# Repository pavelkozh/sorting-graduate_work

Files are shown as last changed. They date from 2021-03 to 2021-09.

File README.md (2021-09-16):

# Проект сортировочного автомата, выполненного на базе микроконтроллера AVR ATmega328P.
Автомат осуществляет сортировку цветных объектов в реальном времени, распределяя их по отдельным емкостям.
Пример работы автомата:



### Алгоритм работы автомата

1. Считывание цвета объекта, проходящего мимо датчика цвета в канале автомата.
2. Формирование очереди объектов для сортировки.
3. Сортировка объектов очереди по принципу FIFO (First Input First Output) с одновременным сдвигом очереди.

Очередь объектов пополняется в режиме реального времени. Сортировка происходит путем подачи последовательности управляющих воздействий на серводвигатели, осуществляющие выталкивание очередного объекта из накопителя и вращение платформы с емкостями.

### Алгоритм формирования очереди объектов

1. Формирование выборки измерений цвета с периодом 2.5 мс и преобразование измерений цветовой модели RGB в цветовую модель HSV.
2. Обработка выборки измерений (для увеличения вероятности верного определения цвета).
3. Добавление объекта в массив очереди.

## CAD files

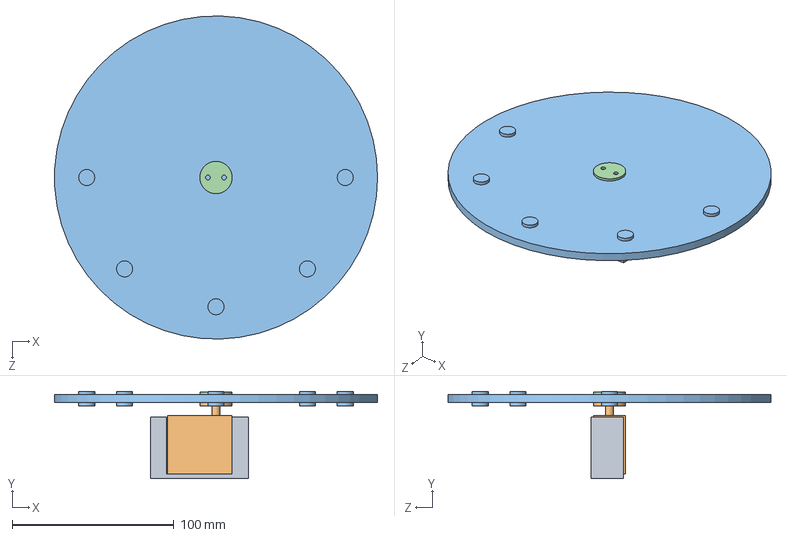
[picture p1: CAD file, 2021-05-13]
blueprints/Сборка2.SLDASM
200.0 x 54.0 x 199.9 mm
for_servo
MG996R
Диск
Шайба

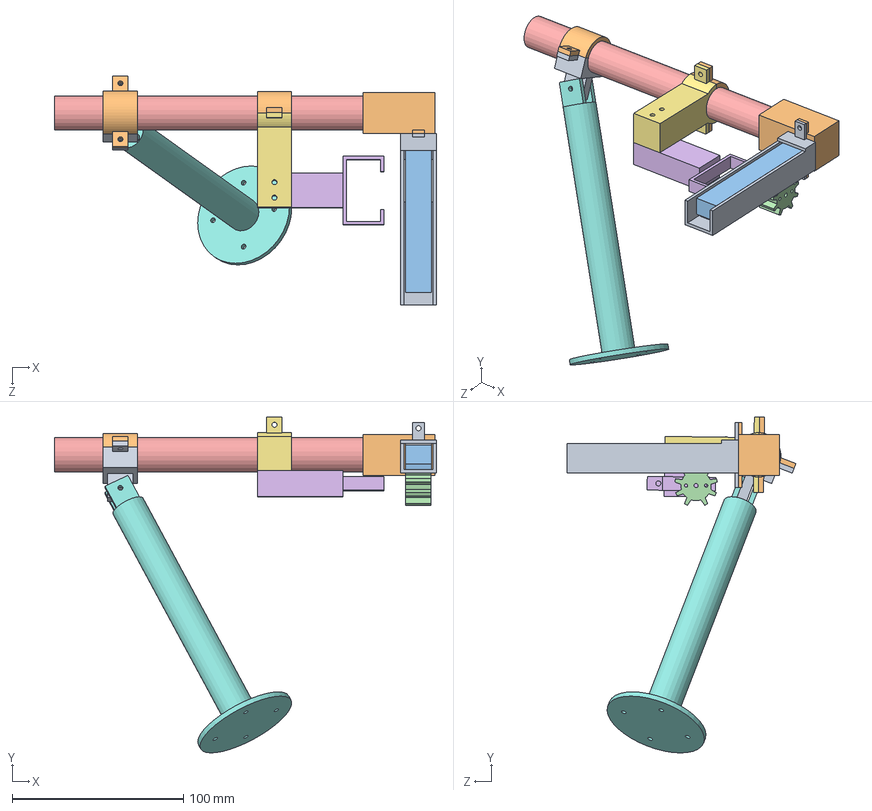
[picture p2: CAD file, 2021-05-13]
blueprints/Сборка.SLDASM
223.0 x 196.1 x 133.6 mm
Желоб
Насадка
Рейка
Шестерня
Труба
Держатель1
Держатель2
Опора
Держатель трубы
Держатель3 x 2

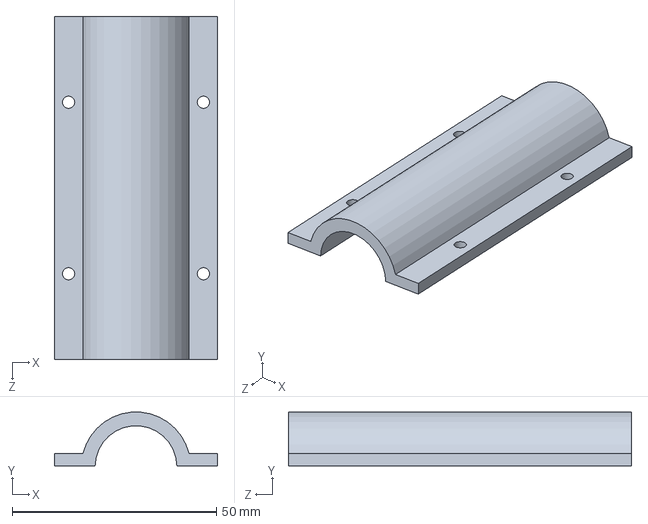
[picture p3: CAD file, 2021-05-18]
blueprints/Соединитель_труб.SLDPRT
40.0 x 13.2 x 84.0 mm

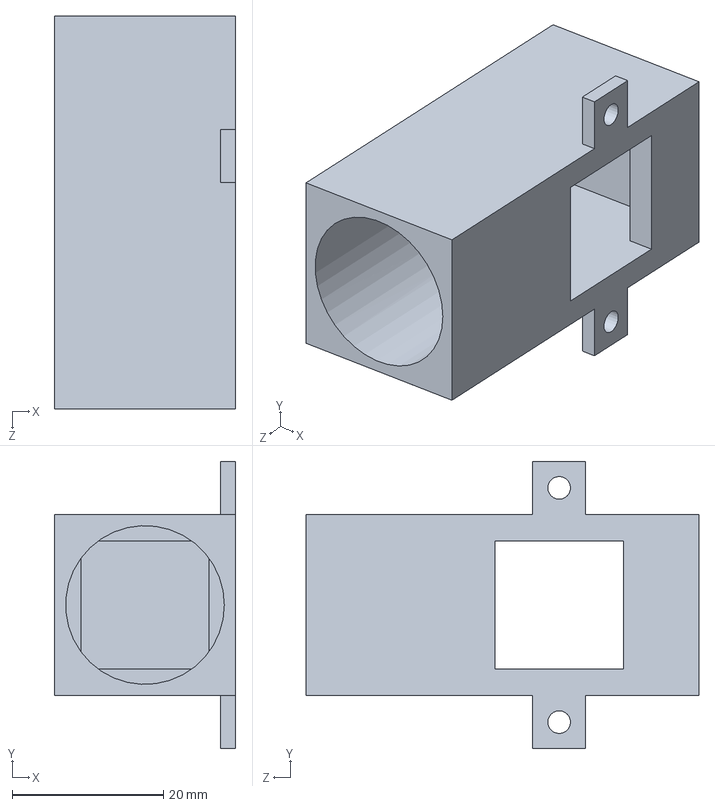
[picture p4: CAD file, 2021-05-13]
blueprints/Насадка_v2.SLDPRT
24.0 x 38.0 x 52.0 mm

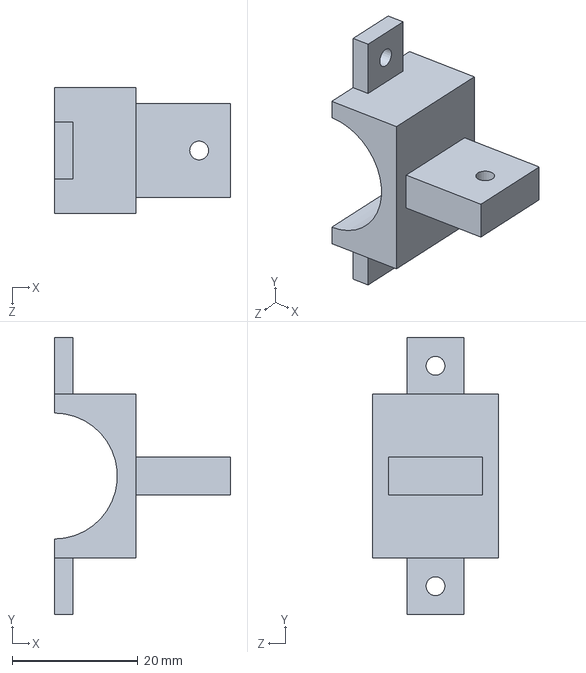
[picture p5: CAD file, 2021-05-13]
blueprints/Держатель трубы.SLDPRT
28.0 x 44.0 x 20.0 mm

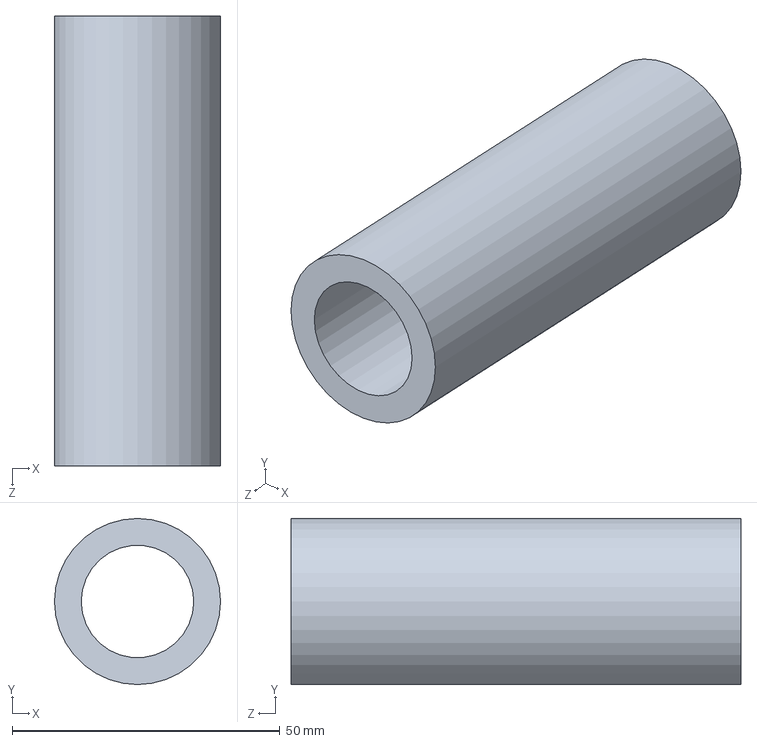
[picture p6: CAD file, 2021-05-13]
blueprints/Соеденитель.SLDPRT
31.0 x 31.0 x 84.0 mm

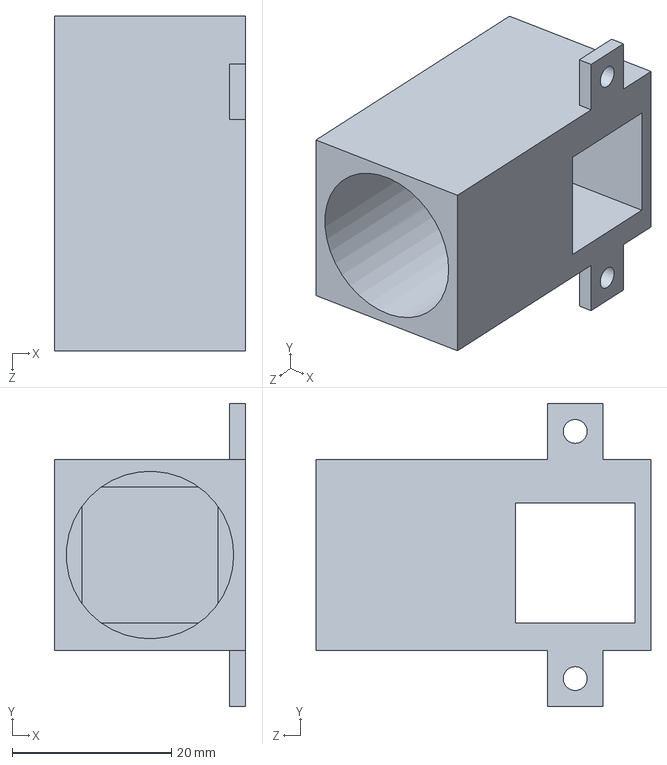
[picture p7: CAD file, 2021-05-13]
blueprints/Насадка.SLDPRT
24.0 x 38.0 x 42.0 mm

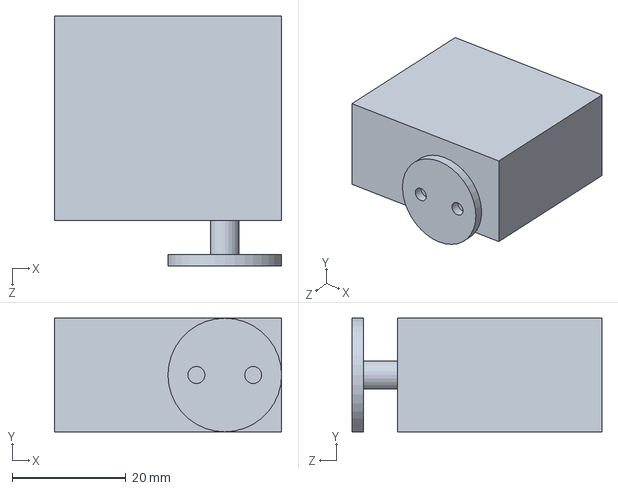
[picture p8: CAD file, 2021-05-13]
blueprints/MG996R.SLDPRT
40.0 x 20.0 x 44.0 mm

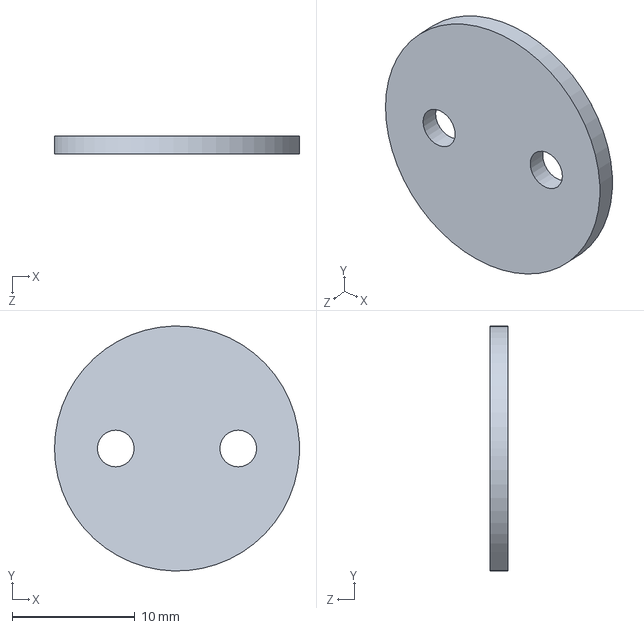
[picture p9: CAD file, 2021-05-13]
blueprints/Шайба.SLDPRT
20.0 x 20.0 x 1.50 mm

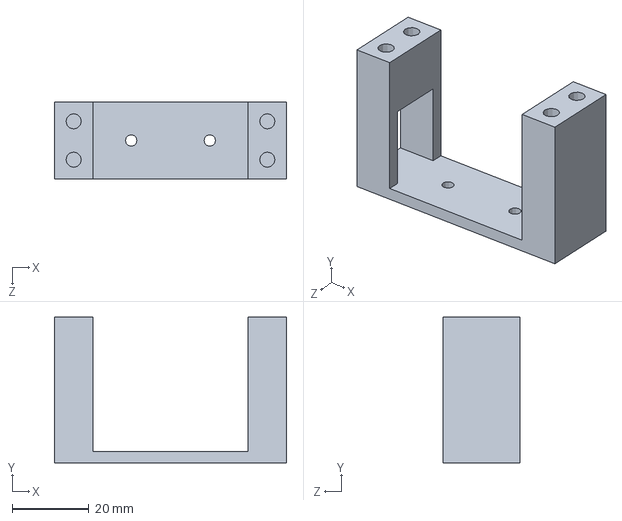
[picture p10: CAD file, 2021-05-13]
blueprints/for_servo.SLDPRT
60.5 x 38.0 x 20.0 mm

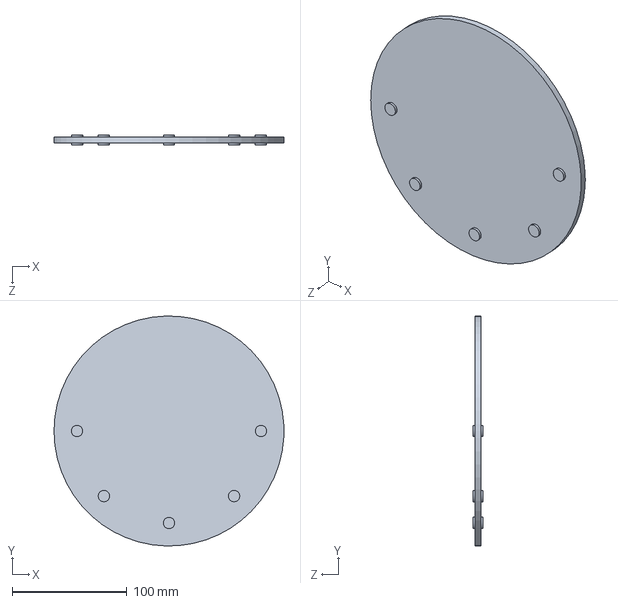
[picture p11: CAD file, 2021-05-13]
blueprints/Диск.SLDPRT
200.0 x 199.9 x 9.00 mm

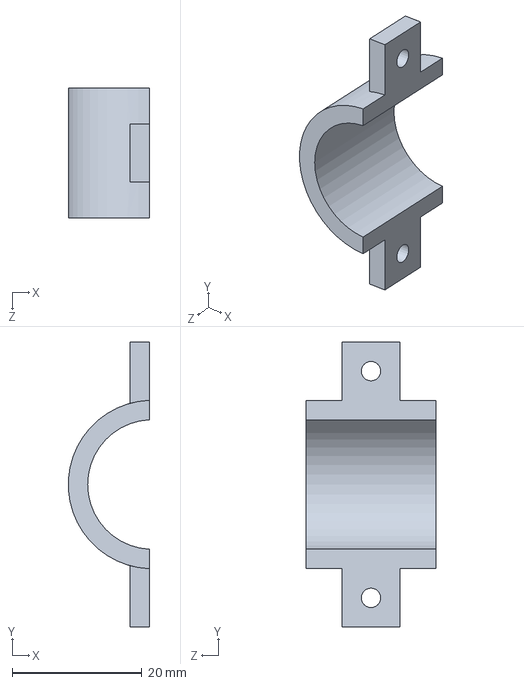
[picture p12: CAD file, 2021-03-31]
blueprints/Держатель3.SLDPRT
12.5 x 44.0 x 20.0 mm

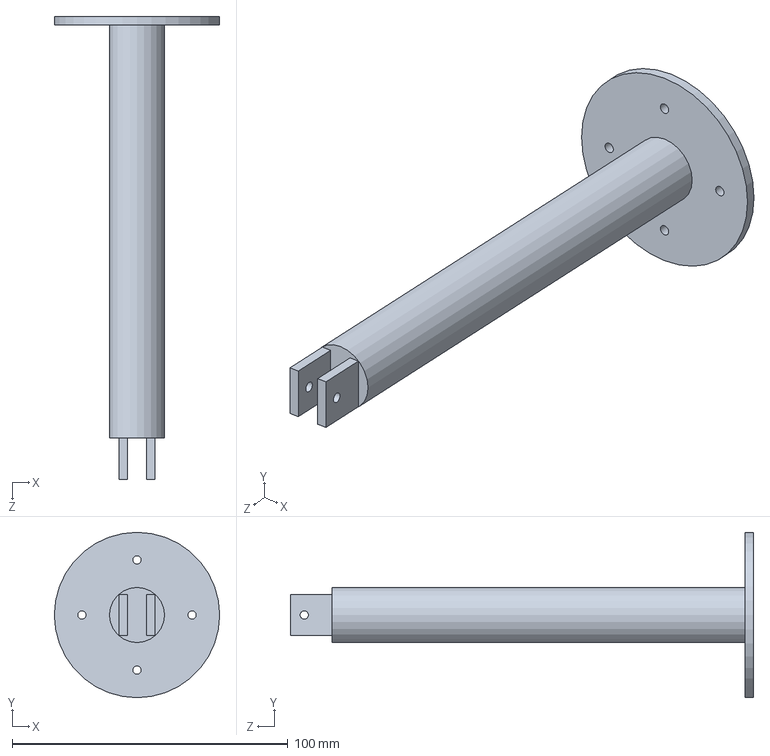
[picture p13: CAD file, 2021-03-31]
blueprints/Опора.SLDPRT
60.0 x 60.0 x 168.0 mm

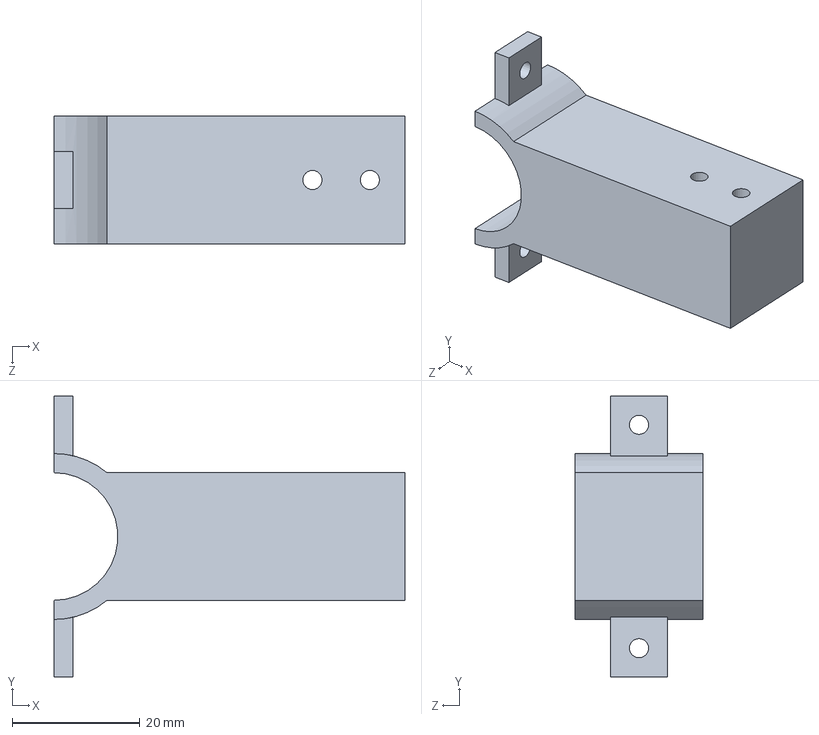
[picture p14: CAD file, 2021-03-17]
blueprints/Держатель2.SLDPRT
55.0 x 44.0 x 20.0 mm

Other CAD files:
blueprints/Держатель1.SLDPRT
blueprints/Труба.SLDPRT
blueprints/Желоб.SLDPRT
blueprints/Шестерня.SLDPRT
blueprints/for_servo.STL
blueprints/Держатель трубы.STL
blueprints/Держатель1.STL
blueprints/Держатель2.STL
blueprints/Держатель3.STL
blueprints/Желоб.STL
blueprints/Насадка.STL
blueprints/Насадка_v2.STL
blueprints/Опора.STL
blueprints/Рейка.SLDPRT
blueprints/Рейка_stl.STL
blueprints/Соеденитель.STL
blueprints/Соединитель_труб.STL
blueprints/Шестерня_stl.STL

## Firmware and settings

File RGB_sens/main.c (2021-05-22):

/*
 * RGB_sens.c
 *
 * Created: 30.10.2020 19:31:41
 * Author : User
 */ 

#define F_CPU 8000000UL
#include <avr/io.h>
#include <avr/interrupt.h>
#include <util/delay.h>
#include <math.h>
#include "i2clib.h"
#include "uartlib.h"
#include "sensorlib.h"
#include "servolib.h"

uint8_t init_sensor_array[10] = {4, SENS_ADDR,0x0F, 0x01, 0x00, 0x00, 0x00, 0xFF, 0x01, 0x03};
uint16_t rgb_array[3] = {0, 0, 0};
float hsv_array[3] = {0, 0, 0};
uint8_t defined_colour=0;
uint8_t shot=0;
uint16_t timer2_counter=0;
uint8_t change_state=1;
uint8_t timeout_rotate=0;
uint8_t timeout_push=0;
uint16_t count=0;
uint8_t line_array[25]={0};
uint8_t ind=0;
uint8_t clear_variables=0;

void clearLine(void){
	
	clear_variables=0;
	defined_colour=0;
	count=0;
	shot=0;
	change_state=1;
	timeout_push=0;
	timeout_rotate=0;
	timer2_counter=0;
	OCR1A=75;//red
	OCR1B=250;//backward
	TIMSK2&=~(1<<1);
	
}

ISR(INT0_vect){
	
	clear_variables=1;
	
}

ISR(INT1_vect){
	
	PORTC^=(1<<0);
	line_array[count]=255;
	count++;
	EIMSK&=~(1<<1);
	
}

ISR (TIMER0_COMPA_vect)
{
	
	defined_colour=getSingleMeasurement(rgb_array,hsv_array);
	if (defined_colour) shot=1;
	
}

ISR (TIMER2_COMPA_vect)
{
	
	timer2_counter++;
	if (timer2_counter==50){
		
		timer2_counter=0;
		updateServoState();
		change_state=1;
	}
	
}
	
int main(void)
{
	//uint16_t count=0;
	//uint8_t line_array[20]={0};
	uint8_t sample_array[200] = {0};//array for sample measurement
	uint8_t cut_sample_array[200] = {0};//array for sample measurement
	//uint8_t ind=0;	
	
	EICRA|=(1<<3)|(1<<1);
	EIMSK|=(1<<1)|(1<<0);
	DDRC = 0x07;
	usartInit(UBRR_VALUE);
	sensorInit(init_sensor_array);
	servoInit();
	timer0Init();
	timer2Init();
	PORTC|=(1<<0);
	sei();

	while (1){
		
		if(clear_variables) clearLine();
		ind=0;
		//PORTC = 0;
		if(defined_colour) {
			
			//PORTC = 1;
			do
			{
				if(shot){
	
					ind=getSampleArray(defined_colour,sample_array,ind);
					shot=0;
					//usartTransmitFloat(hsv_array[0]);
				}
				
			} while (defined_colour);
			//usartTransmitArray(sample_array,ind,1);
			uint16_t cut_array_size=cutArray(sample_array,cut_sample_array,ind);
			//usartTransmitArray(cut_sample_array,cut_array_size,1);
			uint8_t most_element=getMostCommonElement(cut_sample_array,cut_array_size);
			usartTransmit(1);
			usartTransmit(most_element);
			line_array[count]=most_element;
			if(count<49) count++;			

		}
		else //usartTransmitFloat(-1.0);
		usartTransmit(0);//black


		if(count>0){
			
			if(change_state){
				
				if(getServoState()==0){
					uint16_t ang=chooseAngle(line_array[0]);
					servoRotate(ang);
					servoPush(BACKWARD);
					startTimer2();
					change_state=0;	
				}
				
				if(getServoState()==1){
			
					servoPush(FORWARD);
					shiftArray(line_array,count);
					count--;
					change_state=0;	
				}

			}

		}

	}
}

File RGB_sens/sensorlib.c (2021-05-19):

#include "sensorlib.h"

uint8_t flag=1;
static float max_value,min_value,a;

void timer0Init(void){
	
	TCCR0A|=(1<<1);      //CTC mode
	TCCR0B|=(1<<2); // prescale 256
	TIMSK0|=(1<<1);//enable interrupt OCRA0
	OCR0A=0x4E;//   8000000/256 * 2,5e-3 = 78 (4E in hex) - 2.5 ms
}

void sensorInit(uint8_t *init_array){
	
	TWBR |= (1 << TWBR5);// TWBR=32 (for 100 kHz i2c frequency)

	for (int i = 0; i < init_array[0]; i++){
		
		i2cStart();
		i2cWrite(init_array[1] << 1);// 7 bit RGB sensor's address + W (0)
		i2cWrite( (1 << 7) | init_array[2+i] );//select register
		i2cWrite( init_array[6+i] );//write init value
		if(i == 2) _delay_ms(3);
		i2cStop();
	}

}

void readColour(uint16_t *rgb_array){
	
	i2cStart();
	i2cWrite(SENS_ADDR << 1);// 7 bit RGB sensor's address + W (0)
	i2cWrite( (1 << 7) | (1 << 5) | RDATAL_ADDR );// DATAL byte
	
	i2cStart();
	i2cWrite( (SENS_ADDR << 1) | (1 << 0) );// 7 bit RGB sensor's address + R (1)
	
	uint8_t low_data_value = i2cRead();
	uint8_t high_data_value = i2cRead();
	rgb_array[0] = (high_data_value << 8) | low_data_value;
	
	low_data_value = i2cRead();
	high_data_value = i2cRead();
	rgb_array[1] = (high_data_value << 8) | low_data_value;
	
	low_data_value = i2cRead();
	high_data_value = i2cRead();
	rgb_array[2] = (high_data_value << 8) | low_data_value;
	
}

void startConvertion(void){

	// PON Enable (AEN is enabled after every ADC cycle)
	
	i2cStart();
	i2cWrite( SENS_ADDR << 1 );// 7 bit RGB sensor's address + W (0)
	i2cWrite( (1<<7) | 0x00 );
	i2cWrite(0x01);
	i2cStop();
	
}

uint8_t rgb2hsv(uint16_t* in_rgb_array, float* out_hsv_array){

	if(flag==1){
		
		     max_value = 50;
		     min_value = 0;
		     a = 1 / (max_value - min_value);
			flag=0;
	}


	float norm_max_value = 0;
	float norm_min_value = 0;

    float r = ( in_rgb_array[0] - min_value ) * a;
    float g = ( in_rgb_array[1] - min_value ) * a;
    float b = ( in_rgb_array[2] - min_value ) * a;
    
    if( (r >= g) && (r >= b) ) norm_max_value = r;
    else if ( (g >= r) && (g >= b) ) norm_max_value = g;
    else if( (b >= r) && (b >= g) ) norm_max_value = b;
    
    if( (r <= g) && (r <= b) ) norm_min_value = r;
    else if ( (g <= r) && (g <= b) ) norm_min_value = g;
    else if( (b <= r) && (b <= g) ) norm_min_value = b;
	
    if( norm_max_value == norm_min_value ) return 0; //colour not defined
    
    //S
    if( norm_max_value == 0 ) out_hsv_array[1] = 0;
    else out_hsv_array[1] = 1 - norm_min_value / norm_max_value;
    
    //H
	float range = 60 / ( norm_max_value - norm_min_value );
	
    if( (norm_max_value == r) && (g >= b) )
    out_hsv_array[0] = (g - b) * range;
	
    if ( (norm_max_value == r) && (g < b) )
    out_hsv_array[0] = (g - b) * range + 360;
	
    if (norm_max_value == g)
    out_hsv_array[0] = (b - r) * range + 120;
	
    if (norm_max_value == b)
    out_hsv_array[0] = (r - g) * range + 240;
	
	//V
	out_hsv_array[2] = norm_max_value;
    
    return 1;//colour defined
    }

uint8_t getColourCode(float *hsv_array){
	
	if ( (hsv_array[0] >= 350) || (hsv_array[0] < 10) ) return 1;//Code of red colour
	else if ( (hsv_array[0] >= 10) && (hsv_array[0] < 30) ) return 2;//Code of orange colour
	else if ( (hsv_array[0] >= 30) && (hsv_array[0] < 80) ) return 3;//Code of yellow colour
	else if ( (hsv_array[0] >= 80) && (hsv_array[0] < 150) ) return 4;//Code of green colour
	else if ( (hsv_array[0] >= 150) && (hsv_array[0] < 215) ) return 5;//Code of light blue colour
	else if ( (hsv_array[0] >= 215) && (hsv_array[0] < 270) ) return 6;//Code of blue colour
	else if ( (hsv_array[0] >= 270) && (hsv_array[0] < 350) ) return 7;//Code of pink colour
}

uint16_t cutArray(uint8_t *input_array,uint8_t *output_array, uint16_t num_of_elements){
	
	uint16_t low_edge = num_of_elements*0.1;
	uint16_t high_edge = num_of_elements*0.9;
	uint16_t out_count_elements = high_edge-low_edge;
	for(uint16_t j = 0; j < out_count_elements; j++){
		output_array[j] = input_array[j+low_edge];
	}
	return out_count_elements;
}

uint8_t getSingleMeasurement(uint16_t* rgb_array_pointer, float* hsv_array_pointer){

	readColour(rgb_array_pointer);

	if ( rgb2hsv(rgb_array_pointer, hsv_array_pointer) ) {
		uint8_t colour_code = getColourCode(hsv_array_pointer);
		startConvertion();
		return(colour_code);//return colour code
	}
	startConvertion();
	return(0); //colour is not defined (black)
	
}

uint8_t getMostCommonElement(uint8_t *array, uint16_t size_of_array){
	
	uint8_t colour_array[7]={0};//array of elements containing the frequency of each colour
	uint8_t var=0;//secondary variable for sorting colour_array
	uint8_t sec_array[7]={0}; // copy of filled colour_array
	
	for (uint16_t i = 0; i < size_of_array; i++){// filling the colour_array

		switch (array[i])
		{
		case 1:
			colour_array[0]++;
			break;
		case 2:
			colour_array[1]++;
			break;
		case 3:
			colour_array[2]++;
			break;
		case 4:
			colour_array[3]++;
			break;
		case 5:
			colour_array[4]++;
			break;
		case 6:
			colour_array[5]++;
			break;
		case 7:
			colour_array[6]++;
			break;

		}
	}
	
	for (uint8_t i = 0; i < 7; i++){//copying colour_array
		
		sec_array[i] = colour_array[i];
	}
	
	for(uint8_t j = 0; j < 6; j++){// max element will move to the end of the sec_array
		
		if(sec_array[j] > sec_array[j+1]){
			
			var = sec_array[j+1];
			sec_array[j+1] = sec_array[j];
			sec_array[j] = var;
		}
	}
	
	for (uint8_t i = 0; i < 7;i++){
		
		if(colour_array[i] == sec_array[6]) return (i+1);
	}
	
}

uint16_t getSampleArray(uint8_t defined_colour, uint8_t* sample_array, uint16_t elem_index){

		sample_array[elem_index] = defined_colour;
		elem_index+=1;
		if(elem_index > 199) elem_index = 199;
		return elem_index;	
}

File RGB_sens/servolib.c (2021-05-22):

#include "servolib.h"

extern uint8_t timeout_rotate;
extern uint8_t timeout_push;

void servoInit(void){
	
	DDRB|=(1<<1)|(1<<2);
	TCCR1A|=(1<<1)|(1<<7)|(1<<5);      //fast PWM mode; clear on compare match
	TCCR1B|=(1<<4)|(1<<3)|(1<<1)|(1<<0);//fast PWM mode; 64 prescale
	ICR1H=0x09;// period of PWM is 20 ms
	ICR1L=0xC4;
	OCR1A=75;//red
	OCR1B=250;//backward
}

void timer2Init(void){
	
	TCCR2A|=(1<<1);      //CTC mode
	TCCR2B|=(1<<2)|(1<<1)|(1<<0); // prescale 1024
	OCR2A=0x9C;//   8000000/1024 * 20e-3 = 156 (9C in hex) - 20 ms
	
}

void startTimer2(void){
	
	TCNT2=0;
	TIFR2|=(1<<1);//interrupt flag OCF2A is cleared
	TIMSK2|=(1<<1);//enable interrupt
	
}

uint16_t chooseAngle(uint8_t colour_code){
	
	uint16_t angle=0;
	
	switch (colour_code)
	{
		case 1:
		angle=75;//0 degrees
		break;
		
		case 2:
		angle=137;//45 degrees
		break;

		case 3:
		angle=200;//90 degrees
		break;

		case 4:
		angle=260;//135 degrees
		break;

		case 5:
		angle=320;//180 degrees
		break;
		
		case 255:
		angle=OCR1A;
		EIFR|=(1<<1);
		EIMSK|=(1<<1);
		break;		
	}
	
	return angle;
	
}

void servoPush(uint16_t direction){
	
	OCR1B=direction;// 50 - 90, 250 - 0
	
}

void servoRotate(uint16_t angle){

	OCR1A=angle;
}

uint8_t getServoState(void){
	
	if( (timeout_rotate == 0) && (timeout_push == 0) ) return 0;
	else if ( (timeout_rotate == 1) && (timeout_push == 0) ) return 1;

}

void updateServoState(void){
	
	switch (getServoState())
	{
		
		case 0:
		
			timeout_rotate=1;
			break;
		
		case 1:
		
			timeout_rotate=0;
			timeout_push=0;
			TIMSK2&=~(1<<1);
			break;
			
	}
}

void shiftArray(uint8_t *array, uint16_t size){

	for(uint8_t i=0;i<size-1;i++){
		
		array[i]=array[i+1];
		
	}
	
	array[size-1]=0;
	
}

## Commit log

2020-09-30 Add files via upload
    Программа, имитирующая работу светофора.
2020-09-30 README.md
    Проверка
2020-10-05 Программа вывода символа на LCD экране
2021-01-02 Update main.c
    В данной версии датчик непрерывно выдает значения содержания цветов (красный, зеленый и синий), сравнивает эти 3 числа по содержанию в исследуемом объекте и в зависимости от наибольшего содержания цв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
    При большем содержании красного цвета зажигается красный светодиод, при большем содержании синего цвета - ЖЕЛТЫЙ светодиод, а при б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
2021-01-12 uart_transmission.m
    Программа для вывода данных с датчика в командное окно Matlab через последовательный порт UART.
2021-01-13 Libraries with functions for i2c protocol
    This library contains functions i2cStart, i2cWrite, i2cRead and i2cStop for data transmissions.
2021-01-13 Matlab script for displaying data
    This script allows to display RGB data from TCS34725 on the Command Window in Matlab.
    The script contains some functions for reading data from serial interface (UART).
2021-01-13 Header file i2clib.h
2021-01-13 File with functions for i2c protocol
2021-01-13 Header file uartlib.h
2021-01-13 File with functions for UART protocol
    File contains functions for:
    1) UART initialization;
    2) reading 8 bits data;
    3) writing 8 bits and 16 bits data.
2021-01-13 Header file sensorlib.h
2021-01-13 File with functions for TCS34725
    This file contains functions for TCS34725 RGB sensor's initialization and reading 16 bits data (result of red, green or blue ADC conversion)
2021-01-17 Update uartlib.h
    Added a function usartTransmitFloat for transmitting float data/
2021-01-17 Update uart_transmission.m
    This function allows to take a single measurement by pressing a key 's' and display a code of colour (0 - red; 1 - yellow; 2 - green; 3 - light blue; 4 - blue; 5 - pink).
    To close UART connection press 'f'.
2021-01-17 Update sensorlib.h
    Added a function rgb2hsv for converting RGB data to HSV data.
    Also added a function getColourCode which returnd a code of defined colour.
2021-01-20 Update sensorlib.h
    Added an orange colour.
2021-01-21 MATLAB script for testing RGB sensor
    This script allows to eliminate errors in a single measurement in determining the color at the edge of the object
2021-02-02 Добавление нормировки и исправление формулы
    [main.c, sensorlib.c]
2021-02-03 Added a blueprints
    [Горка.SLDPRT]
2021-02-18 interrupt by Timer0
2021-02-23 Шестерня
    [Шестерня.SLDPRT, Шестерня_stl.STL]
2021-03-05 Add blueprints
    [Держатель1.SLDPRT, Держатель1.STL, Желоб.SLDPRT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]
2021-03-10 Держатель1
    [Держатель1.SLDPRT, Держатель1.STL]
2021-03-13 Держатель2
    [Держатель2.SLDPRT, Держатель2.STL, Сборка.SLDASM]
2021-03-17 Держатель3+Держатель2
    [Держатель2.SLDPRT, Держатель2.STL, Держатель3.SLDPRT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]
2021-03-17 Держатель3
2021-03-17 blueprint small fix
    [Держатель3.SLDPRT, Держатель3.STL]
2021-03-31 Опора+Держатель трубы
    [Держатель трубы.SLDPRT, Держатель трубы.STL, Опора.SLDPRT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]
2021-04-30 servo holder
    [for_servo.SLDPRT, for_servo.STL]
2021-05-13 Насадкаv2+соединитель
    [MG996R.SLDPRT, for_servo.SLDPRT, Держатель трубы.SLDPRT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]
2021-05-18 соединитель для труб
    [Соединитель_труб.SLDPRT, Соединитель_труб.STL]
2021-09-16 Update README.md
    Описание проекта.
2021-09-16 Update README.md
    Описание проекта
